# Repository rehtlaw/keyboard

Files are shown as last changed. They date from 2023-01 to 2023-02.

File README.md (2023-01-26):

## Build

- make sure `node` and `npm` are installed and up to date
- clone the repo
- run `npm install` inside the repo
- run `npm run gen` to regenerate the pcb file

## quirks

Ergogen's fillets are a little silly and will depending on your settings create little circles around some corners of your outline.
There doesn't seem to be any problem with just deleting them in KiCAD after the PCB generation, so just do that after running 
the generator.

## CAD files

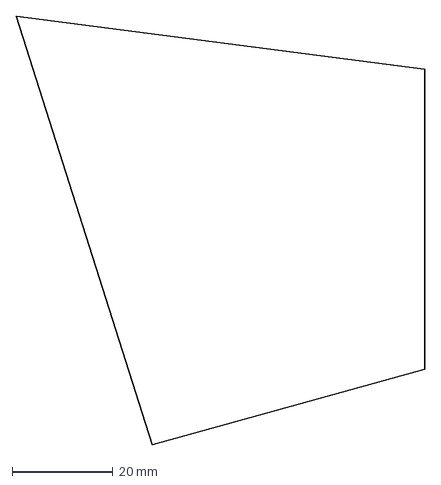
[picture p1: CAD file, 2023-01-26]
output/outlines/bottom_arc_left_intersect.dxf
81.0 x 85.0 mm

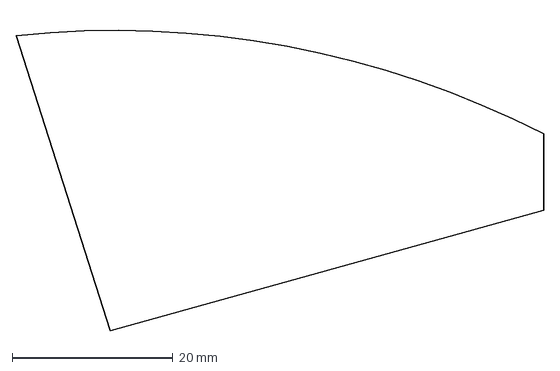
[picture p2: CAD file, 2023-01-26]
output/outlines/arc_bottom_left.dxf
65.7 x 39.1 mm

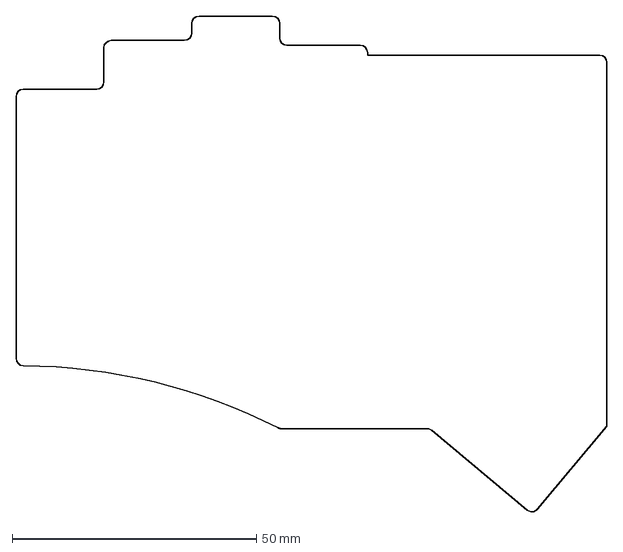
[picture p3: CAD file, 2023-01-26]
output/outlines/pre.dxf
121.0 x 101.6 mm

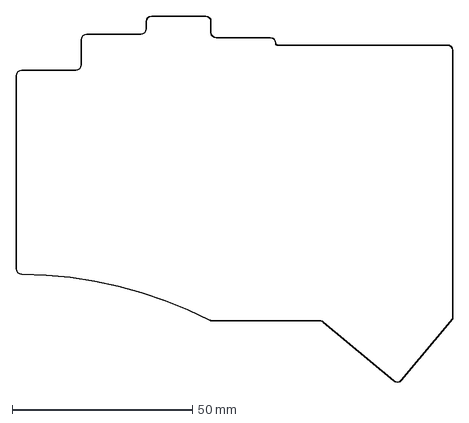
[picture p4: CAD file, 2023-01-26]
output/outlines/cutout.dxf
121.0 x 101.7 mm

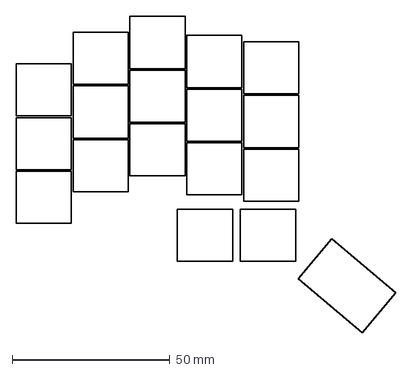
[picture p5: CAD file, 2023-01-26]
output/outlines/preview.dxf
120.2 x 100.1 mm

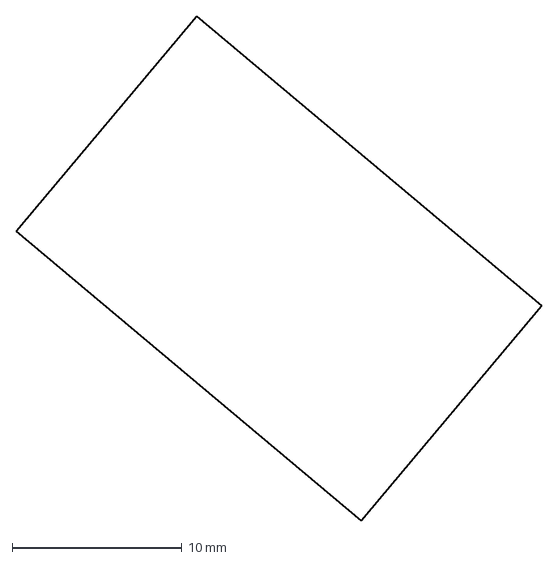
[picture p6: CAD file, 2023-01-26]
output/outlines/keycap_outlines15.dxf
30.9 x 29.7 mm

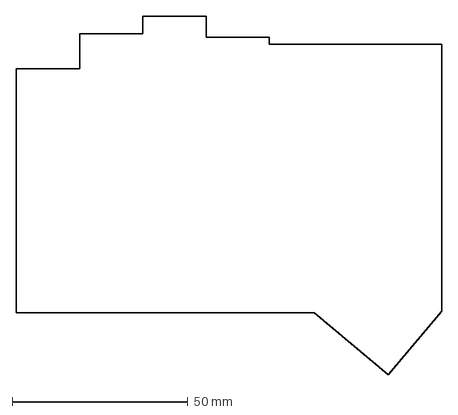
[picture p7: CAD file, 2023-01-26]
output/outlines/raw.dxf
121.0 x 102.1 mm

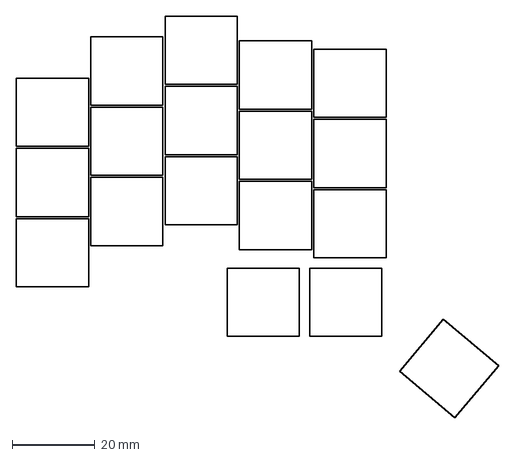
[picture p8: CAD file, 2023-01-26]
output/outlines/keycap_outlines.dxf
116.8 x 97.2 mm

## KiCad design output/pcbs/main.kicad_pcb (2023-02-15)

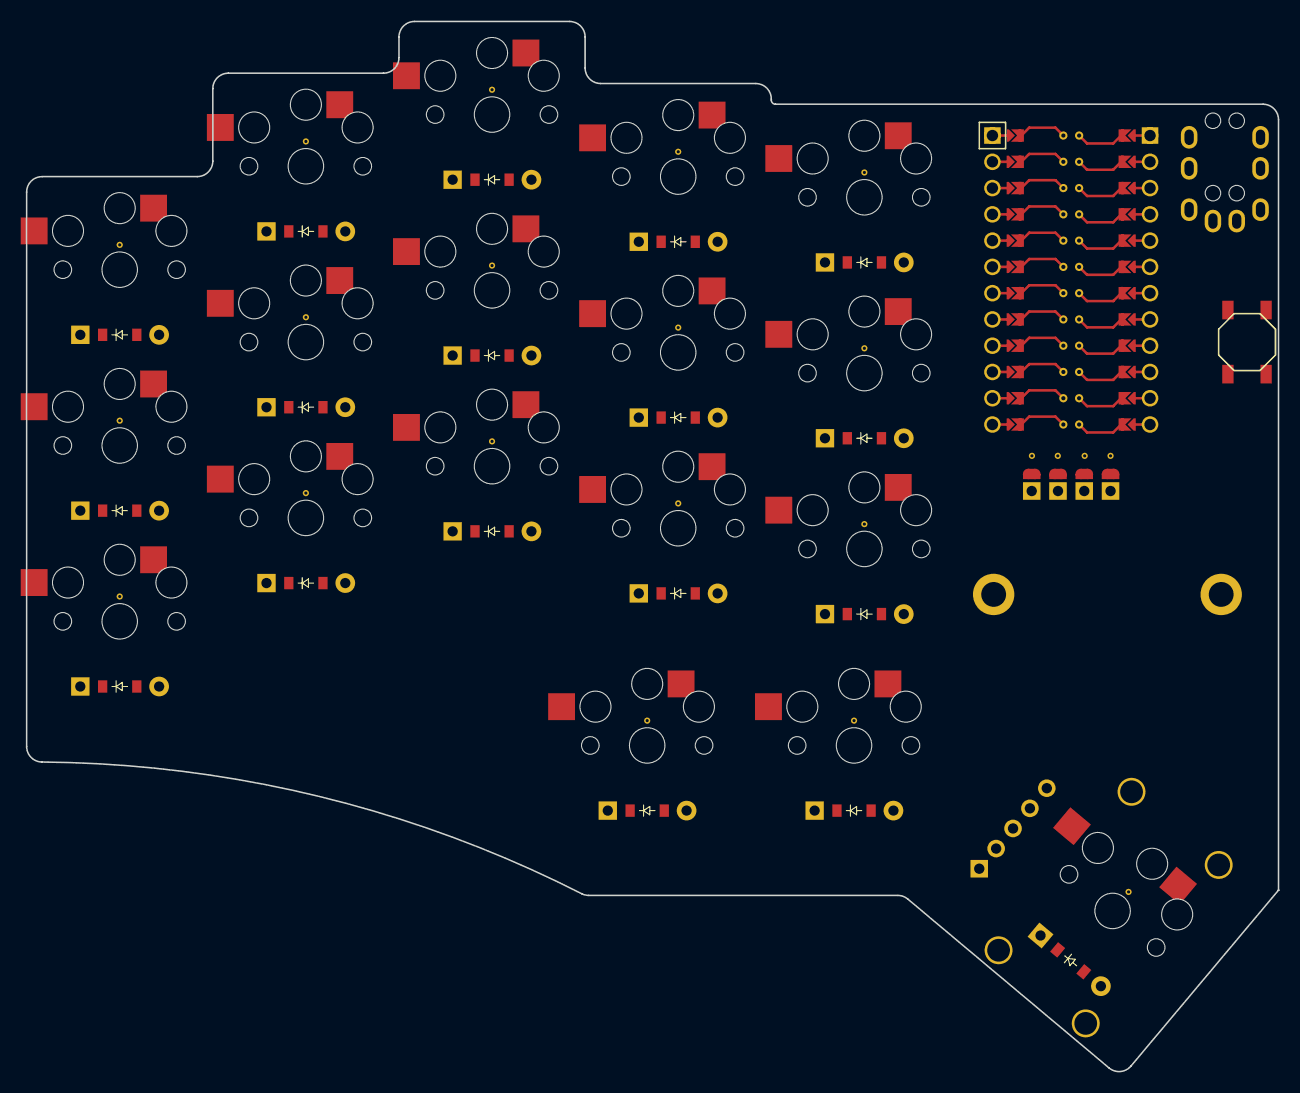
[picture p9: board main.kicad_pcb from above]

Board: 2 copper layers, 121.0 x 101.5 mm, 44 parts (0 on the bottom side), 33 nets, no tracks yet.

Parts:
B1, B2: SW_TACT_ALPS_SKQGABE010
D1, D2, D3, D4, D5, D6, D7, D8, D9, D10, D11, D12, D13, D14, D15, D16, D17, D18: ComboDiode
Mount1: TH1; MountingHole_2.2mm_M2_DIN965_Pad
Mount2: TH2; MountingHole_2.2mm_M2_DIN965_Pad
S1, S2, S3, S4, S5, S6, S7, S8, S9, S10, S11, S12, S13, S14, S15, S16, S17, S18: PG1350
TRRS1: TRRS-PJ-320A-dual
_23: ProMicro
_24: pimoroni_trackball
_25: OLED-double-sided; OLED-128x32-double-sided

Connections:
GND: B1.1, B2.1, TRRS1.3, _23.2, _23.21, _23.22, _25.4
P0: TRRS1.4, _23.23
P2: _23.20, _25.1
P3: _23.19, _25.2
P4: D3.1, D6.1, D9.1, D12.1, D15.1, _23.18
P5: D2.1, D5.1, D8.1, D11.1, D14.1, _23.17
P6: D1.1, D4.1, D7.1, D10.1, D13.1, _23.16
P7: D16.1, D17.1, D18.1, _23.15
P14: S13.2, S14.2, S15.2, S18.2, _23.10
P15: S10.2, S11.2, S12.2, S17.2, _23.9
P18: S7.2, S8.2, S9.2, S16.2, _23.8
P19: S4.2, S5.2, S6.2, _23.7
P20: S1.2, S2.2, S3.2, _23.6
RST: B1.2, B2.2, _23.3
VCC: TRRS1.2, _23.4, _25.3
far_bottom: D13.2, S13.1
far_home: D14.2, S14.1
far_top: D15.2, S15.1
index_bottom: D10.2, S10.1
index_home: D11.2, S11.1
index_top: D12.2, S12.1
inner_main: D16.2, S16.1
middle_bottom: D7.2, S7.1
middle_home: D8.2, S8.1
middle_main: D17.2, S17.1
middle_top: D9.2, S9.1
outer_main: D18.2, S18.1
pinky_bottom: D1.2, S1.1
pinky_home: D2.2, S2.1
pinky_top: D3.2, S3.1
ring_bottom: D4.2, S4.1
ring_home: D5.2, S5.1
ring_top: D6.2, S6.1

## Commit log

2023-01-26 add output folder
    [arc_bottom_left.dxf, bottom_arc_left_intersect.dxf, cutout.dxf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]
2023-01-26 fix PCB + add quirk to readme
    [main.kicad_pcb]
2023-01-26 temporary fix to turn trackball around
    [finished.kicad_pcb, main.kicad_pcb]
2023-01-26 whoops the vias were too close
    [main.kicad_pcb]
2023-01-26 finished PCB, all DRC errors accounted for
    [finished.kicad_pcb]
2023-02-15 add some vias for each switch and the oled footprint
2023-02-15 change one of the through-holes to Mount2 for freerouting
2023-02-15 2 layer edition featuring gerber files
    [finished.kicad_pcb, main.kicad_pcb]
